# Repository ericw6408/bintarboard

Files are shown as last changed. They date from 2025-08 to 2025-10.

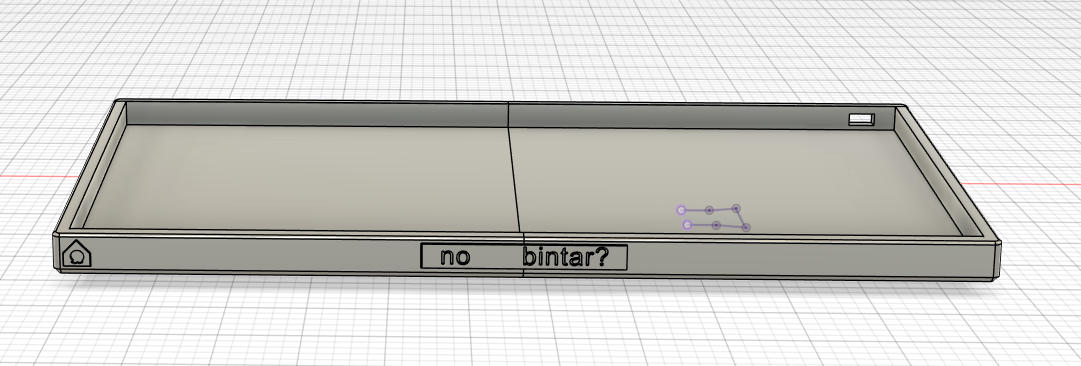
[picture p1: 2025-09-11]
demo/3d design photo/bintarboard case.png

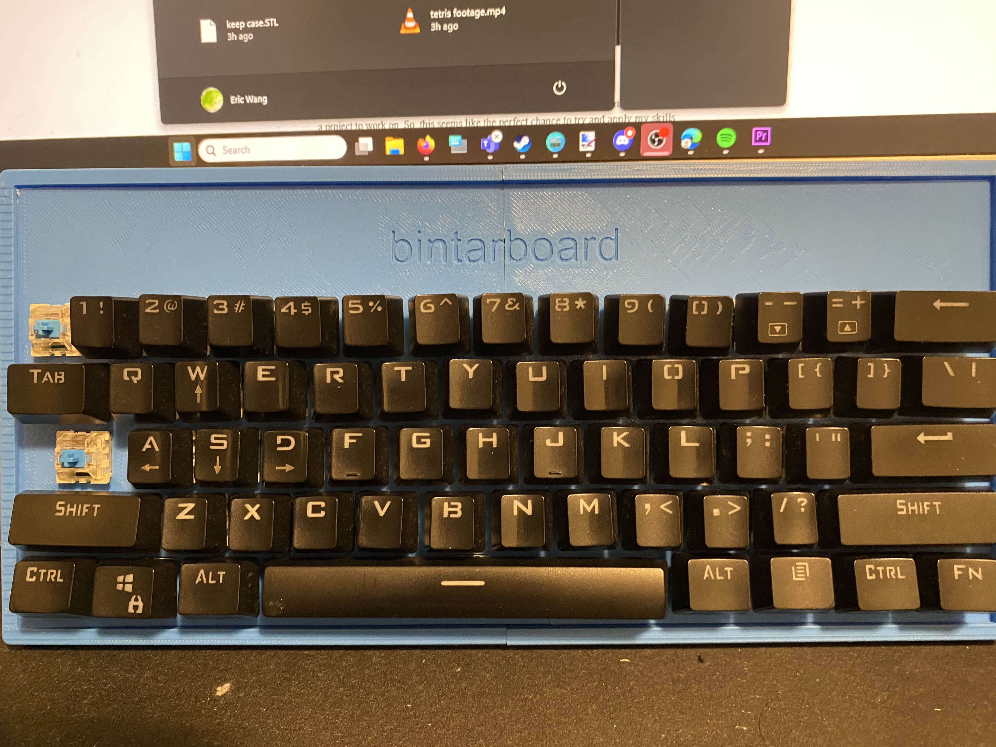
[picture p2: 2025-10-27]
demo/bintarboard.jpg

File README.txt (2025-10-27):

README.txt

Hi!
This is my Capstone project for my high school class! I have built a custom mechanical keyboard from scratch, from prototyping the pcb to designing the case, to building QMK, as well as assembling it together. 

This is my first time doing anything similar to this! YAHOOO

Current:
Soldered PCB, printed case and plate, and assembled.
Unfortunately, RDP protection was enabled, which means that flashing code onto the STM32 processor isn't possible. 

General overview of the project on https://youtu.be/W4MYoR_t5gU

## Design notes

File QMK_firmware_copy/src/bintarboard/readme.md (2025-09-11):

# bintarboard

bintarboard 

*A short description of the keyboard/project*

* Keyboard Maintainer: [ericw](https://github.com/ericw6408)
* Hardware Supported: *the pcb found on github*
* Hardware Availability: *nowhere lol*

Flashing example for this keyboard using QMK Msys:

qmk compile -kb *path to parent directory of src files* -km default

## Bootloader

Enter the bootloader via the:

* **Physical reset button**: Briefly press the button on the back of the PCB - some may have pads you must short instead

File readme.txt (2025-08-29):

Project folder for my Capstone - to build a functioning mechanical keyboard from scratch (pcb & 3d design)

important links;

OVERALL DRIVE (contains important links) - https://drive.google.com/drive/u/4/folders/18o9uerfq0x_WH1BaW3ACFQj0hwd5xBWN

DESIGN OVERVIEW - https://docs.google.com/document/d/1KXGB5h3ZsnleX6CWxwtBgmpEKm-P6IIhk3RWb0EpCBA/edit?usp=sharing

JOURNAL - https://docs.google.com/document/d/1J6AVzHMcLJOE-DcdarVPnF8WTttvT12hYWETaq9IW7c/edit?usp=sharing

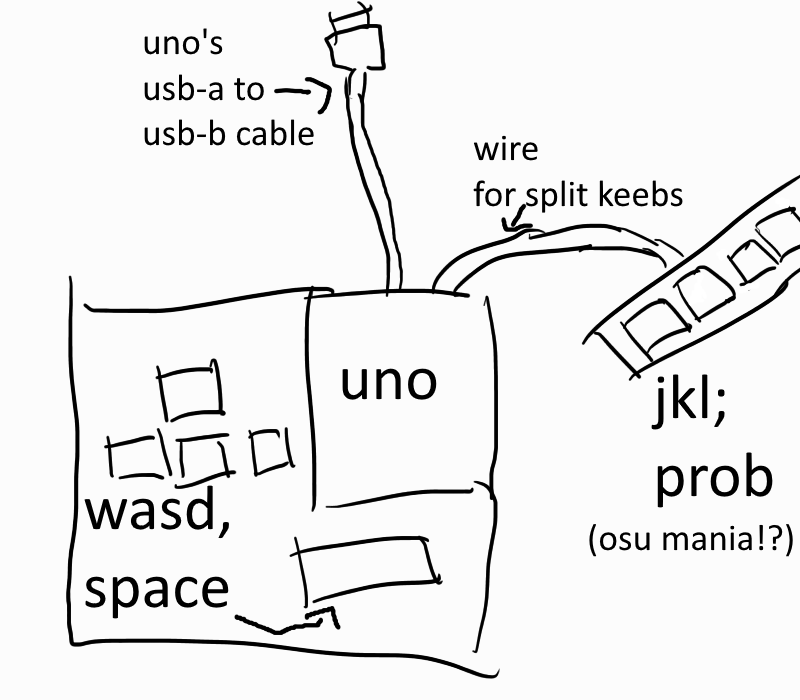
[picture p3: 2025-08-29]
Keypad design.png

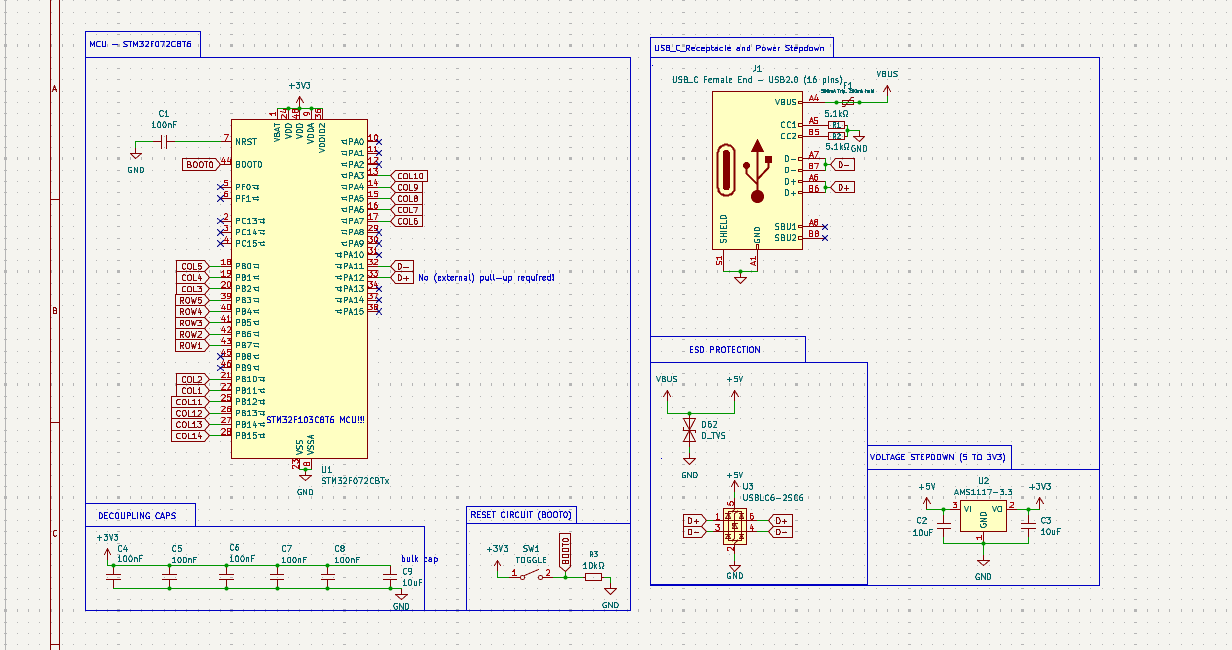
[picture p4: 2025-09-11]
demo/pcb and schematic photo/MCU and related schematic.png

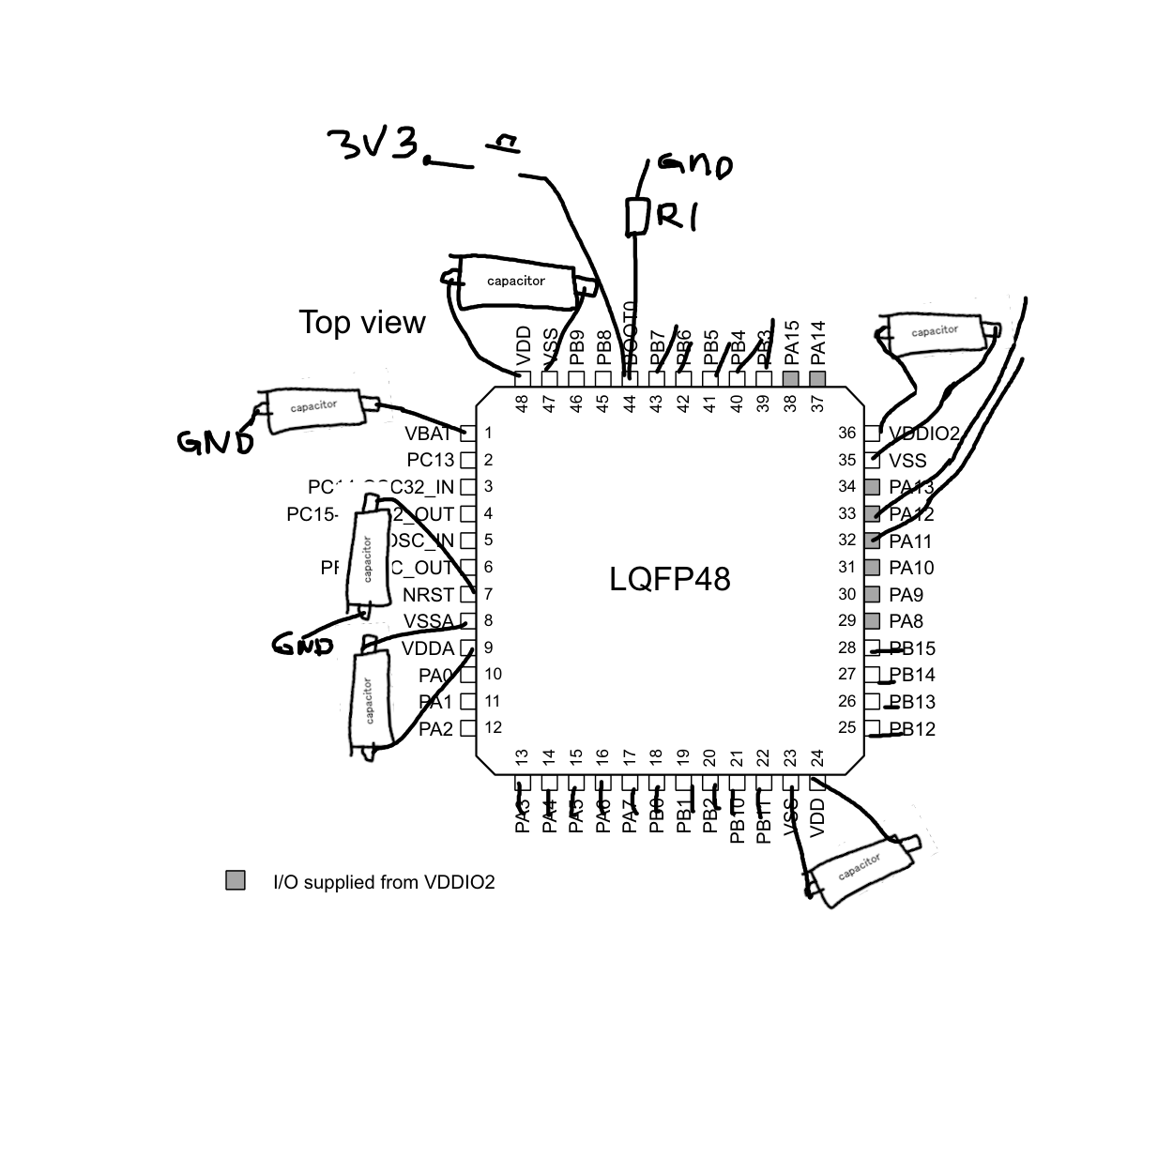
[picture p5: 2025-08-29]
datasheets/stm32 pinout.png

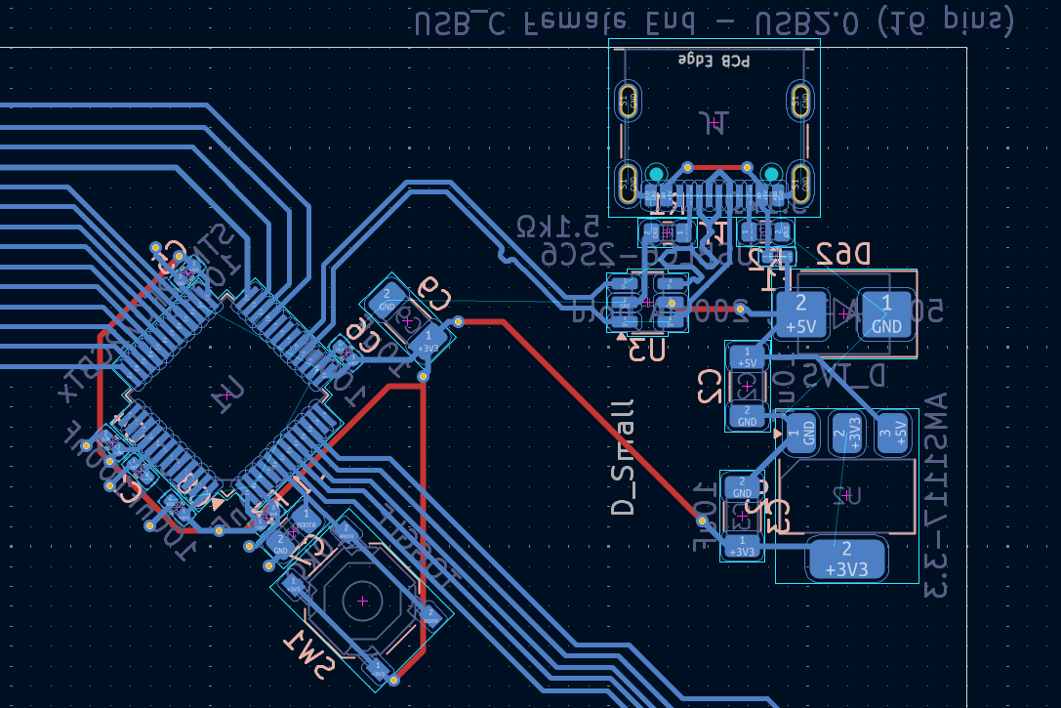
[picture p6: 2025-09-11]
demo/pcb and schematic photo/mcu and voltage stepdown and esd proection.png

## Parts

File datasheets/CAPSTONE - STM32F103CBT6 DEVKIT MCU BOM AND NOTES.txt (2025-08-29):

CAPSTONE - STM32 DEVKIT MCU / DEVKIT IMPLEMENTATION

BOM:

MCU -  STM32F072CBT6 (EXTENDED)
USB-C RECEPTACLE - G-Switch GT-USB-7017A //JLCPCB C22383818 (12 pin) (EXTENDED)
RESISTOR 5.1k - 0603WAF5101T5E
RESISTOR 10k - 0805W8F1002T5E 
RESETTABLE FUSE 500mA Trip / 200mA Hold - BSMD0402L-020 (EXTENDED)
CAPACITOR 100nF - CL05B104KO5NNNC 
CAPACITOR 10uF - TAJA106K016RNJ
TVS / ESD protection - USBLC6-2SC6 / P6SMB6.8CA/TR13
5V to 3.3V VOLTAGE STEPDOWN - AMS1117-3.3
PUSHBUTTON SWITCH - TS-1187A-B-A-B
DIODE FAST RECOVERY TIME - 1N4148WS 

AFTER DOING SOME RESEARCH I NEED:

GENERAL:
	DECOUPLING CIRCUIT ON EACH FREAKING POWER INPUT: DONE
	FUSE & ESD PROTECTION: (the resettable fuse) DONE
	VOLTAGE STEPDOWN: DONE
	RESET SWITCH: DONE
	BOOT SWITCH: DONE
	USB CONNECTION: DONE
MATRIX:
	WORKING ON IT!

https://youtu.be/aVUqaB0IMh4

TODOLIST:

SETUP PCB FOR JLCPCB (https://youtu.be/WAIb_Lq7LCg)
WIRE UP MY MATRIX 
WIRE UP MY USB-C CONNECTOR TO FUSE AND ESD PROTECTION AND STEPDOWN

WIRE STEPDOWN TO DECOUPLING FOR STM32
WIRE MATRIX TO STM32

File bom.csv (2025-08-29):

Designator | Footprint | Quantity | Value | LCSC Part #
C1, C4, C5, C6, C7, C8 | 0402 | 6 | 100nF | C1525
C2, C3, C9 | 1206 | 3 | 10uF | C7171
D1, D10, D11, D12, D13, D14, D15, D16, D17, D18, D19, D2, D20, D21, D22, D23, D24, D25, D26, D27, D28, D29, D3, D30, D31, D32, D33, D34, D35, D36, D37, D38, D39, D4, D40, D41, D42, D43, D44, D45, D46, D47, D48, D49, D5, D50, D51, D52, D53, D54, D55, D56, D57, D58, D59, D6, D60, D61, D7, D8, D9 | D_SOD-323 | 61 | D_Small | C2128
D62 | D_SMB | 1 | D_TVS | C78395
F1 | 0402 | 1 | 500mA Trip, 200mA hold | C914085
J1 | USB_C_Receptacle_GCT_USB4105-xx-A_16P_TopMnt_Horizontal | 1 | USB_C Female End - USB2.0 (16 pins) | C22383818
R1, R2 | 0603 | 2 | 5.1kΩ | C23186
R3 | 0805 | 1 | 10kΩ | C17414
SW1 | SW_Push_1P1T_XKB_TS-1187A | 1 | TOGGLE | C318884
U1 | LQFP-48_7x7mm_P0.5mm | 1 | STM32F072CBTx | C81720
U2 | SOT-223-3_TabPin2 | 1 | AMS1117-3.3 | C6186
U3 | SOT-23-6 | 1 | USBLC6-2SC6 | C7519

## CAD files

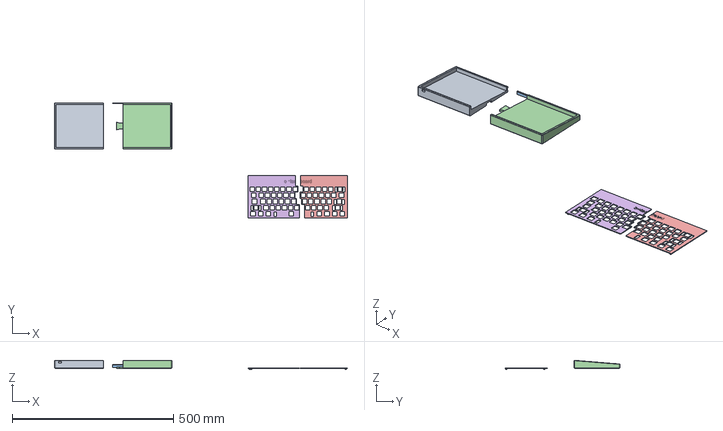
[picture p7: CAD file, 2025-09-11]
3D DESIGN/case and plate version 2.step
908.2 x 357.9 x 28.4 mm

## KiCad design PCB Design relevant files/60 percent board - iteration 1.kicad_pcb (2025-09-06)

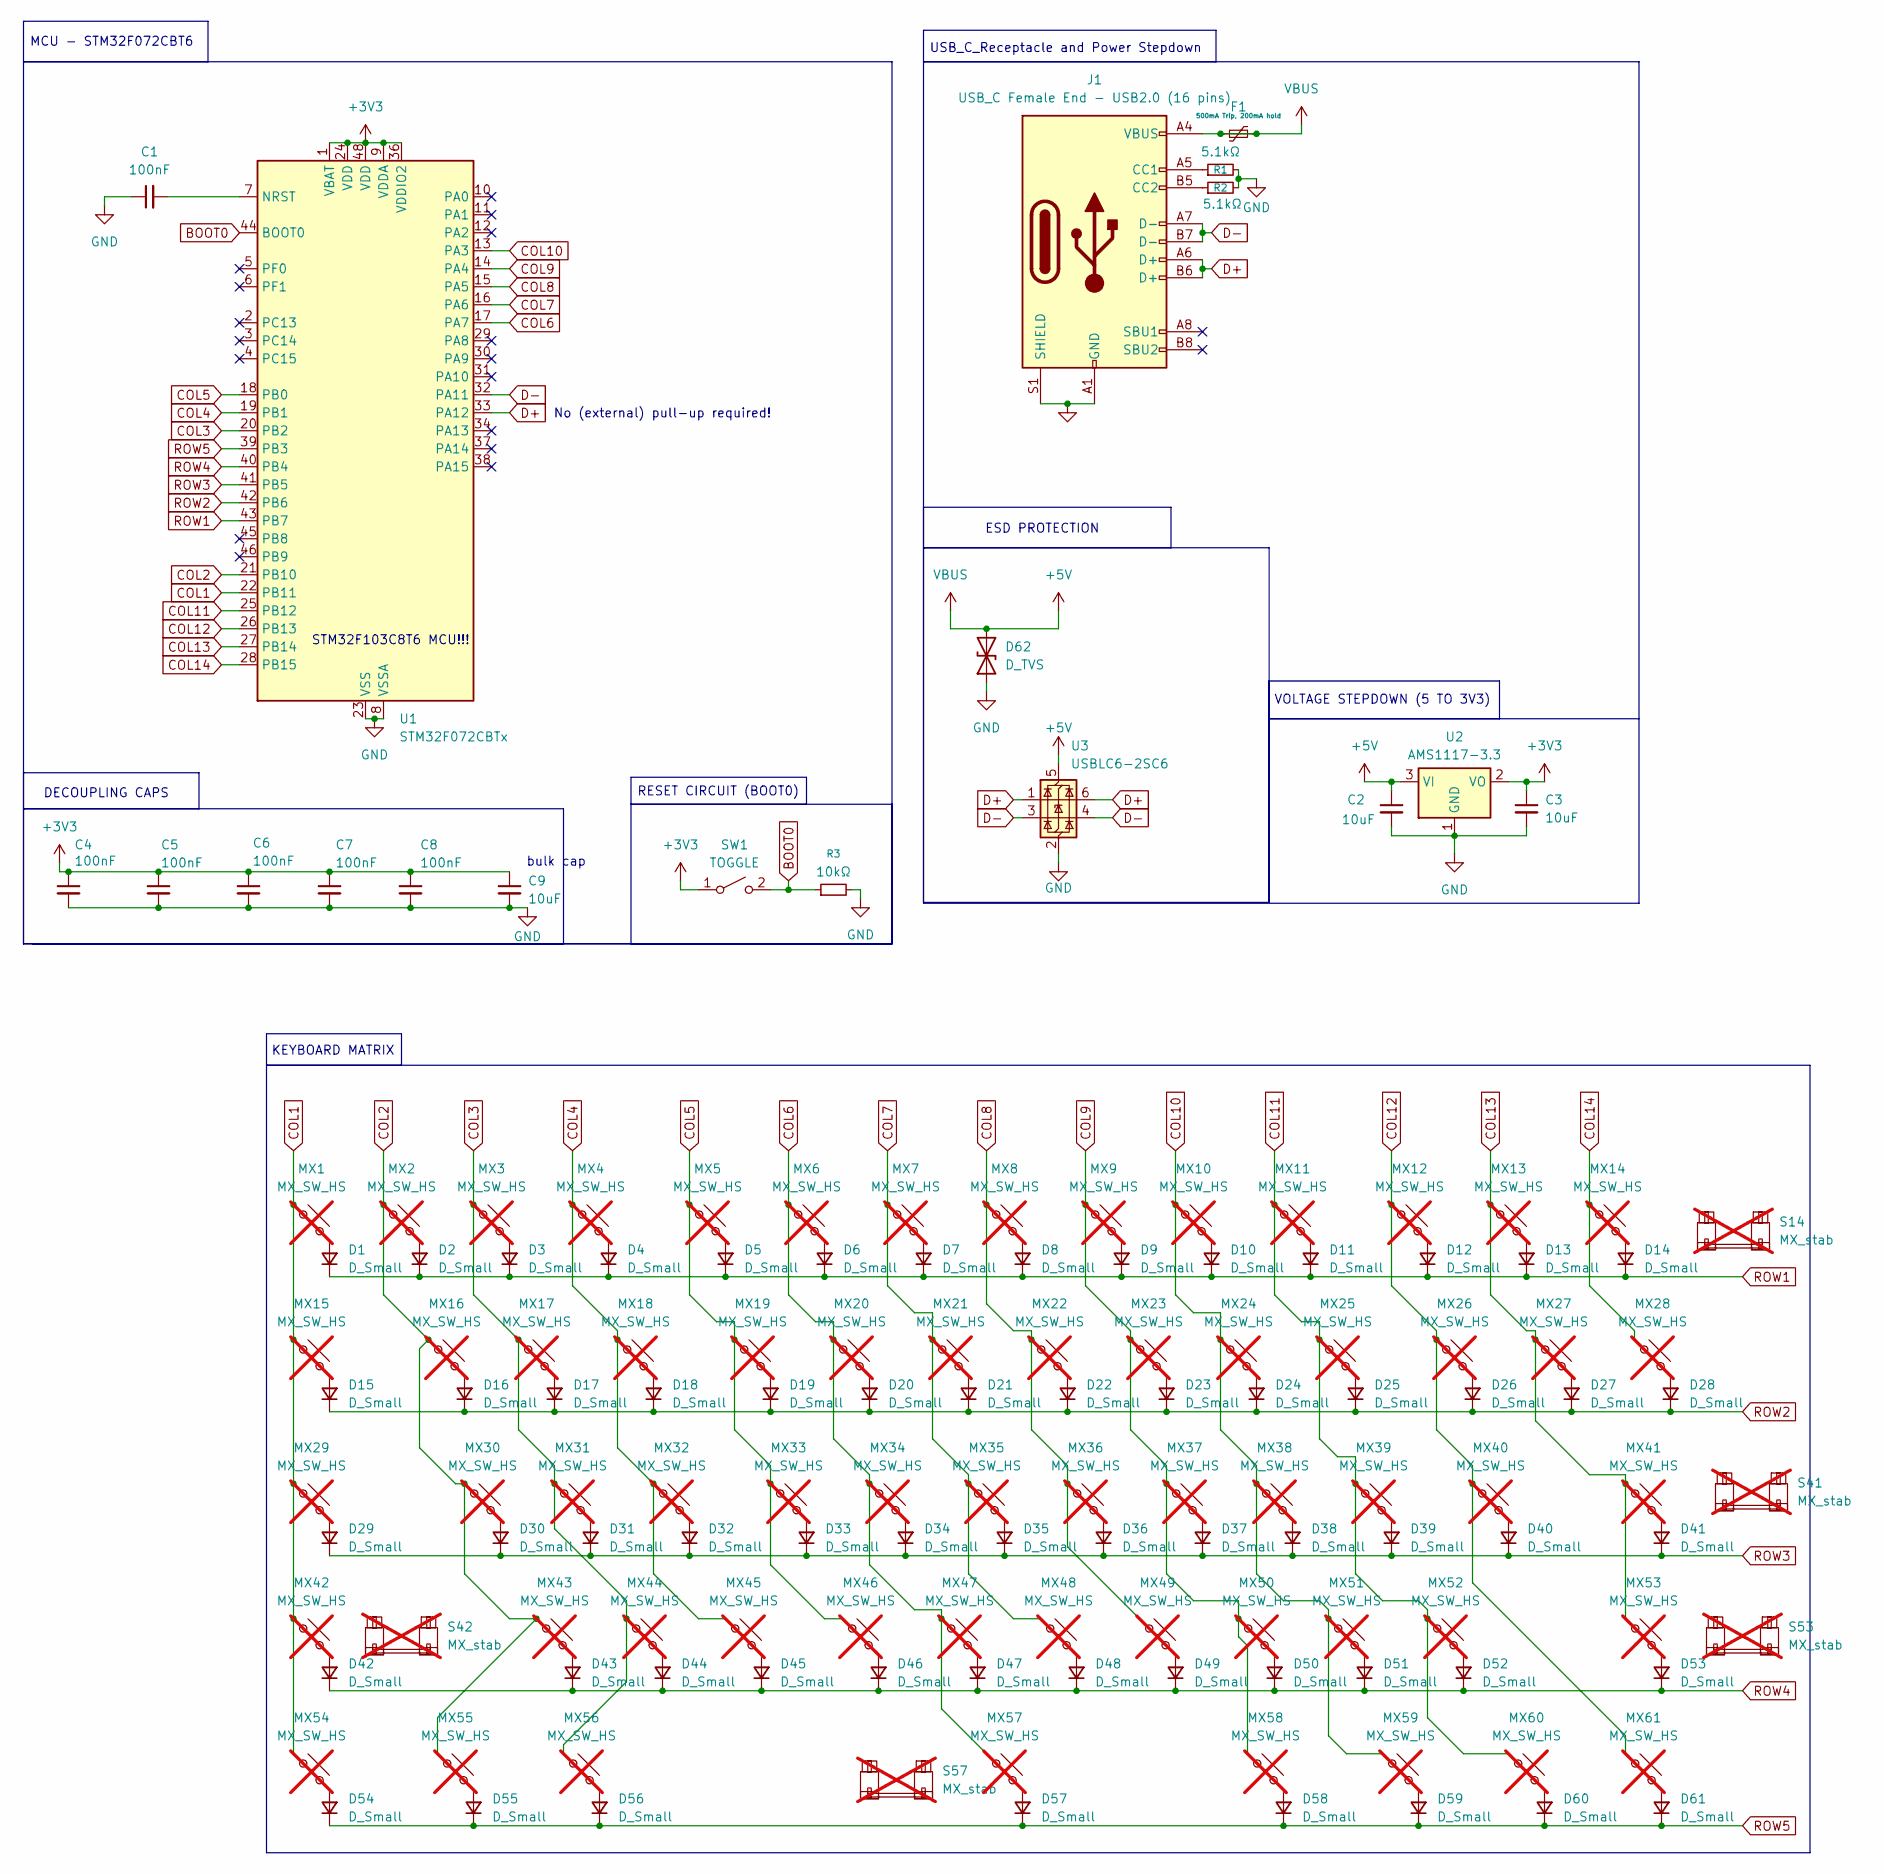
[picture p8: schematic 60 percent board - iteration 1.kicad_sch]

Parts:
C1, C4, C5, C6, C7, C8: 100nF; C_0402_1005Metric
C2, C3, C9: 10uF; C_1206_3216Metric
D1, D2, D3, D4, D5, D6, D7, D8, D9, D10, D11, D12, D13, D14, D15, D16, D17, D18, D19, D20, D21, D22, D23, D24, D25, D26, D27, D28, D29, D30, D31, D32, D33, D34, D35, D36, D37, D38, D39, D40, D41, D42, D43, D44, D45, D46, D47, D48, D49, D50, D51, D52, D53, D54, D55, D56, D57, D58, D59, D60, D61: D_Small; D_SOD-323
D62: D_TVS; D_SMB
F1: 500mA Trip, 200mA hold; Fuse_0402_1005Metric
J1: USB_C Female End - USB2.0 (16 pins); USB_C_Receptacle_GCT_USB4105-xx-A_16P_TopMnt_Horizontal
MX1, MX2, MX3, MX4, MX5, MX6, MX7, MX8, MX9, MX10, MX11, MX12, MX13, MX16, MX17, MX18, MX19, MX20, MX21, MX22, MX23, MX24, MX25, MX26, MX27, MX30, MX31, MX32, MX33, MX34, MX35, MX36, MX37, MX38, MX39, MX40, MX43, MX44, MX45, MX46, MX47, MX48, MX49, MX50, MX51, MX52: MX_SW_HS; SW_Hotswap_Kailh_MX_1.00u; not fitted
MX14: MX_SW_HS; SW_Hotswap_Kailh_MX_2.00u; not fitted
MX15, MX28: MX_SW_HS; SW_Hotswap_Kailh_MX_1.50u; not fitted
MX29: MX_SW_HS; SW_Hotswap_Kailh_MX_1.75u; not fitted
MX41, MX42: MX_SW_HS; SW_Hotswap_Kailh_MX_2.25u; not fitted
MX53: MX_SW_HS; SW_Hotswap_Kailh_MX_2.75u; not fitted
MX54, MX55, MX56, MX58, MX59, MX60, MX61: MX_SW_HS; SW_Hotswap_Kailh_MX_1.25u; not fitted
MX57: MX_SW_HS; SW_Hotswap_Kailh_MX_6.25u; not fitted
R1, R2: 5.1kΩ; R_0603_1608Metric
R3: 10kΩ; R_0805_2012Metric
S14, S41, S42, S53: MX_stab; STAB_MX_P_2u; not fitted
S57: MX_stab; STAB_MX_P_6.25u; not fitted
SW1: TOGGLE; SW_Push_1P1T_XKB_TS-1187A
U1: STM32F072CBTx; LQFP-48_7x7mm_P0.5mm
U2: AMS1117-3.3; SOT-223-3_TabPin2
U3: USBLC6-2SC6; SOT-23-6

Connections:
+3V3: C3.1, C4.1, C5.1, C6.1, C7.1, C8.1, C9.1, SW1.1 (A), U1.1 (VBAT), U1.9 (VDDA), U1.24 (VDD), U1.36 (VDDIO2), U1.48 (VDD), U2.2 (VO)
+5V: C2.1, D62.2 (A2), F1.1, F1.2, J1.A4 (VBUS), J1.A9 (VBUS), J1.B4 (VBUS), J1.B9 (VBUS), U2.3 (VI), U3.5 (VBUS)
BOOT0: R3.1, SW1.2 (B), U1.44 (BOOT0)
COL1: MX1.1, MX15.1, MX29.1, MX42.1, MX54.1, U1.22 (PB11)
COL2: MX2.1, MX16.1, MX30.1, MX43.1, MX55.1, U1.21 (PB10)
COL3: MX3.1, MX17.1, MX31.1, MX44.1, MX56.1, U1.20 (PB2)
COL4: MX4.1, MX18.1, MX32.1, MX45.1, U1.19 (PB1)
COL5: MX5.1, MX19.1, MX33.1, MX46.1, U1.18 (PB0)
COL6: MX6.1, MX20.1, MX34.1, MX47.1, MX57.1, U1.17 (PA7)
COL7: MX7.1, MX21.1, MX35.1, MX48.1, U1.16 (PA6)
COL8: MX8.1, MX22.1, MX36.1, MX49.1, U1.15 (PA5)
COL9: MX9.1, MX23.1, MX37.1, MX50.1, MX58.1, U1.14 (PA4)
COL10: MX10.1, MX24.1, MX38.1, MX51.1, MX59.1, U1.13 (PA3)
COL11: MX11.1, MX25.1, MX39.1, MX52.1, MX60.1, U1.25 (PB12)
COL12: MX12.1, MX26.1, MX40.1, MX61.1, U1.26 (PB13)
COL13: MX13.1, MX27.1, MX41.1, MX53.1, U1.27 (PB14)
COL14: MX14.1, MX28.1, U1.28 (PB15)
D+: J1.A6 (D+), J1.B6 (D+), U1.33 (PA12), U3.1 (I/O1), U3.6 (I/O1)
D-: J1.A7 (D-), J1.B7 (D-), U1.32 (PA11), U3.3 (I/O2), U3.4 (I/O2)
GND: C1.1, C2.2, C3.2, C4.2, C5.2, C6.2, C7.2, C8.2, C9.2, D62.1 (A1), J1.A1 (GND), J1.A12 (GND), J1.B1 (GND), J1.B12 (GND), J1.S1 (SHIELD), R1.2, R2.2, R3.2, U1.8 (VSSA), U1.23 (VSS), U1.35 (VSS), U1.47 (VSS), U2.1 (GND), U3.2 (GND)
unnamed: D1.2 (A), MX1.2
unnamed: D2.2 (A), MX2.2
unnamed: D3.2 (A), MX3.2
unnamed: D4.2 (A), MX4.2
unnamed: D5.2 (A), MX5.2
unnamed: D6.2 (A), MX6.2
unnamed: D7.2 (A), MX7.2
unnamed: D8.2 (A), MX8.2
unnamed: D9.2 (A), MX9.2
unnamed: D10.2 (A), MX10.2
unnamed: D11.2 (A), MX11.2
unnamed: D12.2 (A), MX12.2
unnamed: D13.2 (A), MX13.2
unnamed: D14.2 (A), MX14.2
unnamed: D15.2 (A), MX15.2
unnamed: D16.2 (A), MX16.2
unnamed: D17.2 (A), MX17.2
unnamed: D18.2 (A), MX18.2
unnamed: D19.2 (A), MX19.2
unnamed: D20.2 (A), MX20.2
unnamed: D21.2 (A), MX21.2
unnamed: D22.2 (A), MX22.2
unnamed: D23.2 (A), MX23.2
unnamed: D24.2 (A), MX24.2
unnamed: D25.2 (A), MX25.2
unnamed: D26.2 (A), MX26.2
unnamed: D27.2 (A), MX27.2
unnamed: D28.2 (A), MX28.2
unnamed: D29.2 (A), MX29.2
unnamed: D30.2 (A), MX30.2
unnamed: D31.2 (A), MX31.2
unnamed: D32.2 (A), MX32.2
unnamed: D33.2 (A), MX33.2
unnamed: D34.2 (A), MX34.2
unnamed: D35.2 (A), MX35.2
unnamed: D36.2 (A), MX36.2
unnamed: D37.2 (A), MX37.2
unnamed: D38.2 (A), MX38.2
unnamed: D39.2 (A), MX39.2
unnamed: D40.2 (A), MX40.2
unnamed: D41.2 (A), MX41.2
unnamed: D42.2 (A), MX42.2
unnamed: D43.2 (A), MX43.2
unnamed: D44.2 (A), MX44.2
unnamed: D45.2 (A), MX45.2
unnamed: D46.2 (A), MX46.2
unnamed: D47.2 (A), MX47.2
unnamed: D48.2 (A), MX48.2
unnamed: D49.2 (A), MX49.2
unnamed: D50.2 (A), MX50.2
unnamed: D51.2 (A), MX51.2
unnamed: D52.2 (A), MX52.2
unnamed: D53.2 (A), MX53.2
unnamed: D54.2 (A), MX54.2
unnamed: D55.2 (A), MX55.2
unnamed: D56.2 (A), MX56.2
unnamed: D57.2 (A), MX57.2
unnamed: D58.2 (A), MX58.2
unnamed: D59.2 (A), MX59.2
unnamed: D60.2 (A), MX60.2
unnamed: D61.2 (A), MX61.2
unnamed: J1.A5 (CC1), R1.1
unnamed: J1.B5 (CC2), R2.1
unnamed: C1.2, U1.7 (NRST)
ROW1: D1.1 (K), D2.1 (K), D3.1 (K), D4.1 (K), D5.1 (K), D6.1 (K), D7.1 (K), D8.1 (K), D9.1 (K), D10.1 (K), D11.1 (K), D12.1 (K), D13.1 (K), D14.1 (K), U1.43 (PB7)
ROW2: D15.1 (K), D16.1 (K), D17.1 (K), D18.1 (K), D19.1 (K), D20.1 (K), D21.1 (K), D22.1 (K), D23.1 (K), D24.1 (K), D25.1 (K), D26.1 (K), D27.1 (K), D28.1 (K), U1.42 (PB6)
ROW3: D29.1 (K), D30.1 (K), D31.1 (K), D32.1 (K), D33.1 (K), D34.1 (K), D35.1 (K), D36.1 (K), D37.1 (K), D38.1 (K), D39.1 (K), D40.1 (K), D41.1 (K), U1.41 (PB5)
ROW4: D42.1 (K), D43.1 (K), D44.1 (K), D45.1 (K), D46.1 (K), D47.1 (K), D48.1 (K), D49.1 (K), D50.1 (K), D51.1 (K), D52.1 (K), D53.1 (K), U1.40 (PB4)
ROW5: D54.1 (K), D55.1 (K), D56.1 (K), D57.1 (K), D58.1 (K), D59.1 (K), D60.1 (K), D61.1 (K), U1.39 (PB3)

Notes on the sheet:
USB_C_Receptacle and Power Stepdown
DECOUPLING CAPS
KEYBOARD MATRIX
MCU - STM32F072CBT6
bulk cap
VOLTAGE STEPDOWN (5 TO 3V3)
STM32F103C8T6 MCU!!!
No (external) pull-up required!
ESD PROTECTION
RESET CIRCUIT (BOOT0)

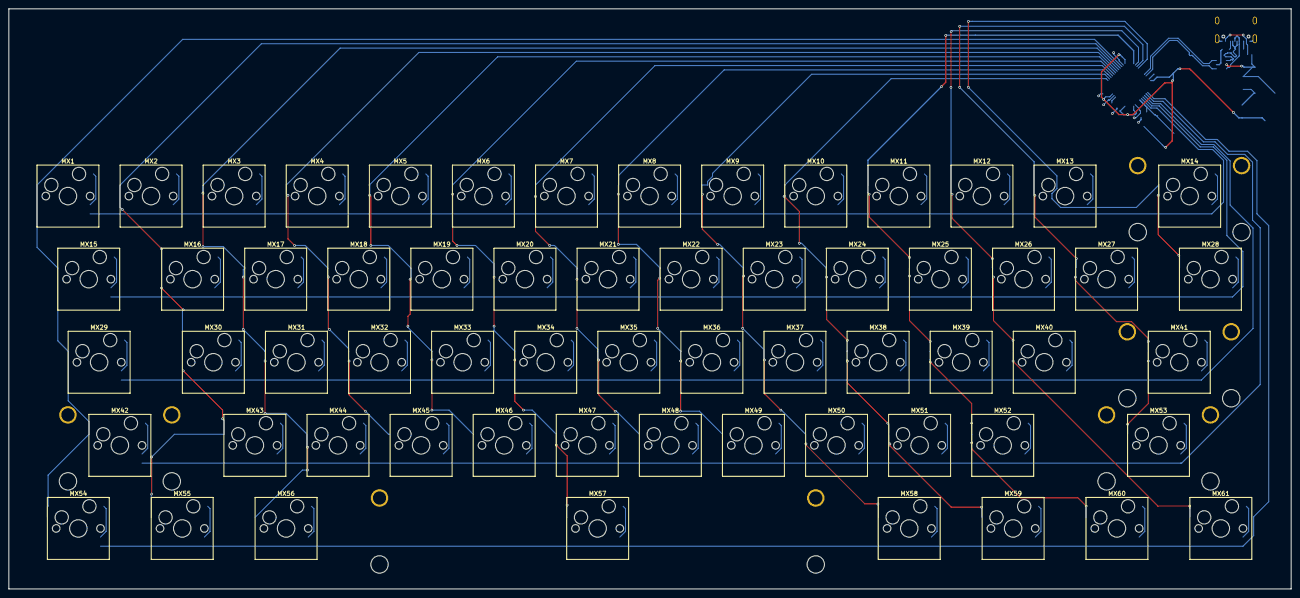
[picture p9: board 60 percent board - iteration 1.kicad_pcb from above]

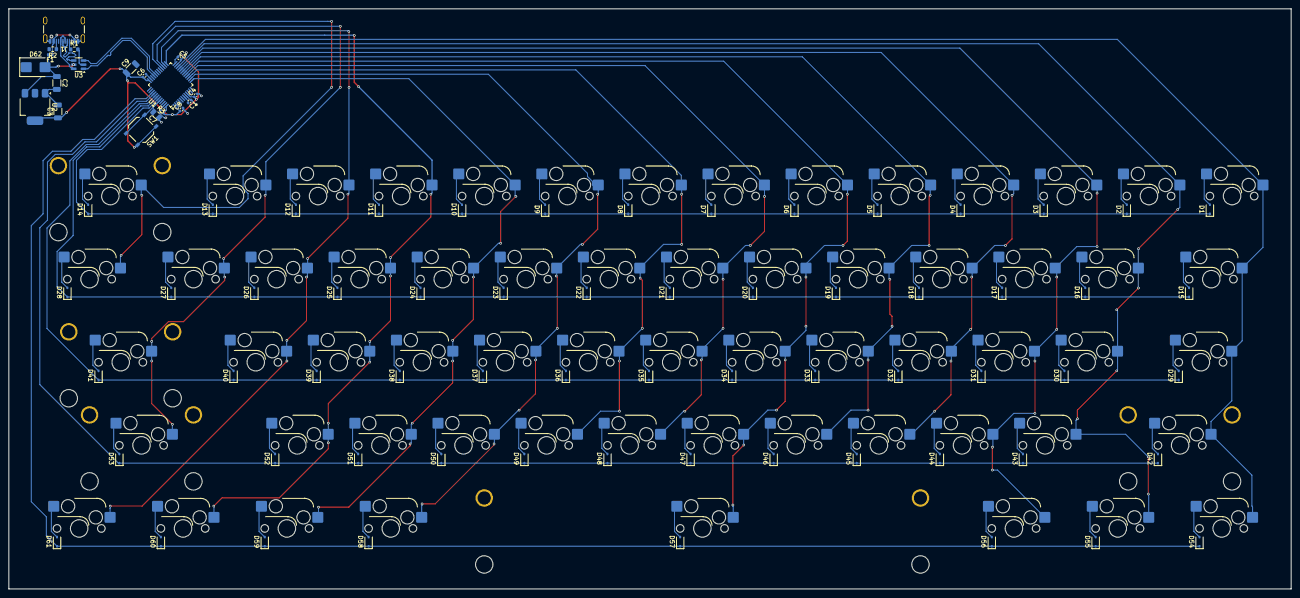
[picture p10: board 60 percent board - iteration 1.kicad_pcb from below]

Board: 2 copper layers, 294.0 x 133.0 mm, 146 parts (80 on the bottom side), 89 nets.

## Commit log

2025-02-11 readme + bill of materials beginning
2025-08-29 initial commit (basically)
    [bom.csv]
2025-09-06 Gerbers, schematic & PCB files for kicad.
    [60 percent board - iteration 1.kicad_pcb, 60 percent board - iteration 1.kicad_sch]
2025-09-11 Case & Plate 3d design files, with tolerances.
    Thanks to my friend for printing this for me! The standoffs were weird.
    [case and plate version 2.step]
2025-10-27 Final image of assembled keyboard.
    THE FREAKING KEYBOARD DOESNT WOOORK :(( (but im proud of it anyway)
